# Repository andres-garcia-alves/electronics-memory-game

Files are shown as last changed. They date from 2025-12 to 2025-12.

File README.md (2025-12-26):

# Memory-Game

Arduino code for a 4 coloured memory game (Simon) 

&nbsp;

This project use the following electronic components:
- 1 x Arduino Nano v3
- 1 x Display 5621AS-1, 7-segments, 2-digit, common catode
- 4 x LEDs (red, blue, yellow & green)
- 1 x Buzzer
- 5 x Push-button
- 8 x 470 ohm resistors
- 4 x 330 ohm resistors
- 1 x Batery 9v

Notes:
- Edit `Definitions.h` to adjust configured display pins to your own display model.

&nbsp;

### Screenshots

| Schematic Diagram | PBC Layout |
|---|---|
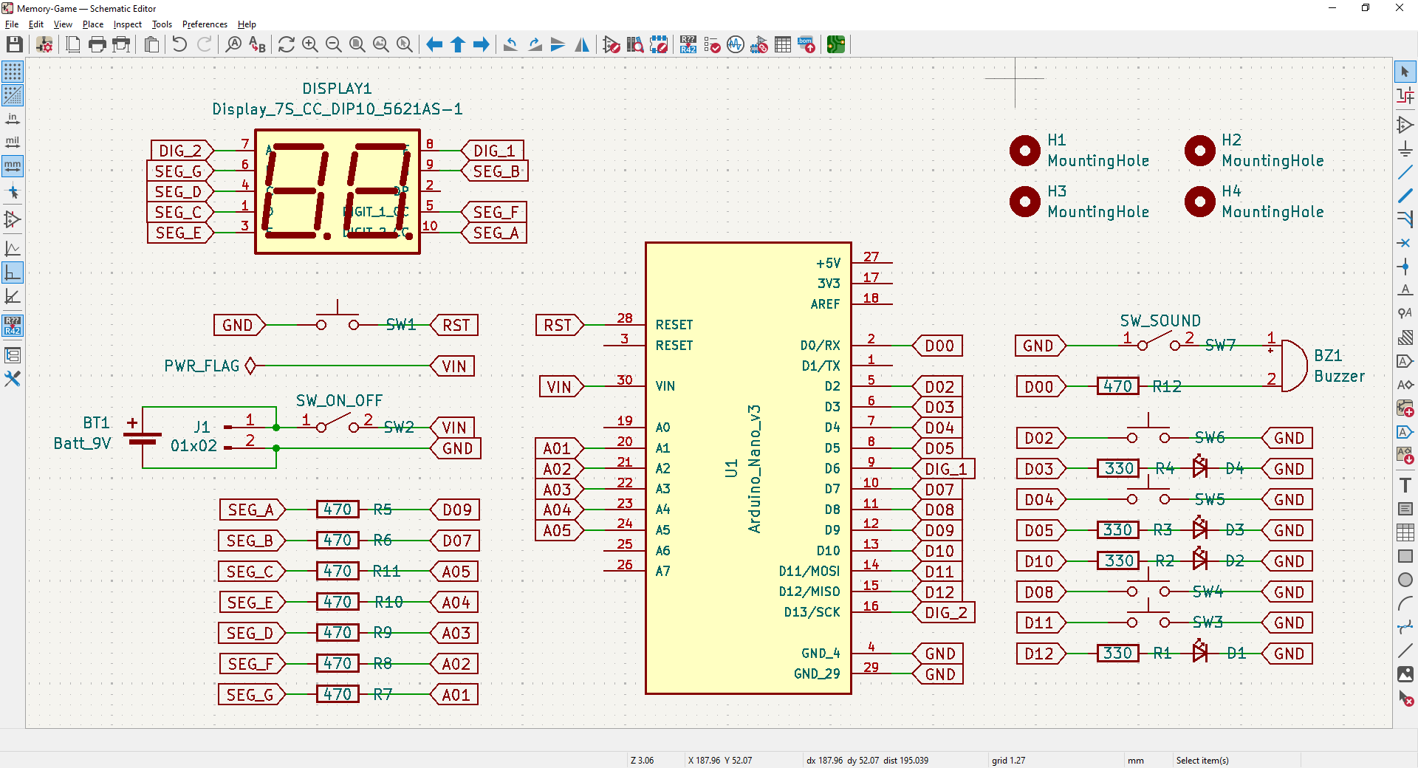
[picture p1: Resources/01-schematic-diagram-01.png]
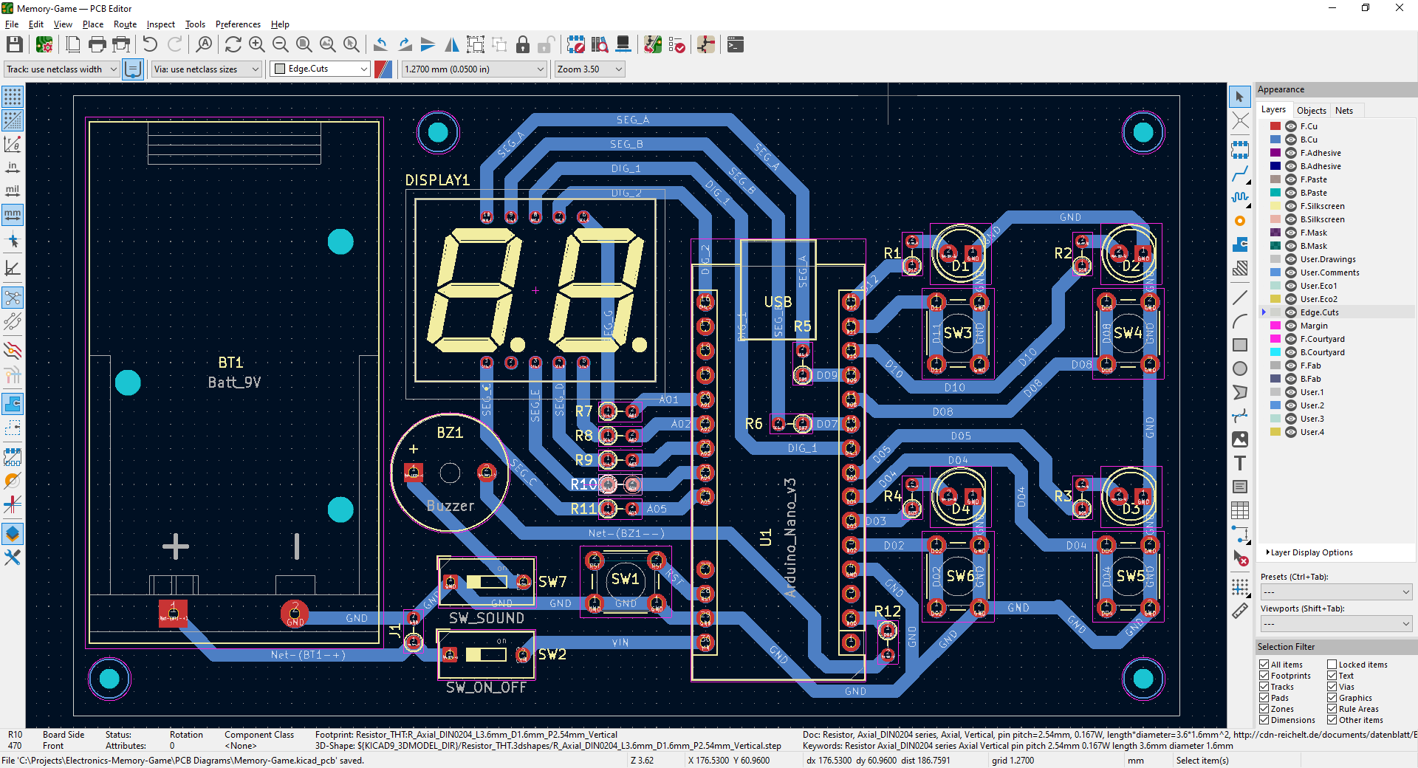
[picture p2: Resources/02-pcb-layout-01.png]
|  |  |

| PCB 3D Render | PBC 3D Render |
|---|---|
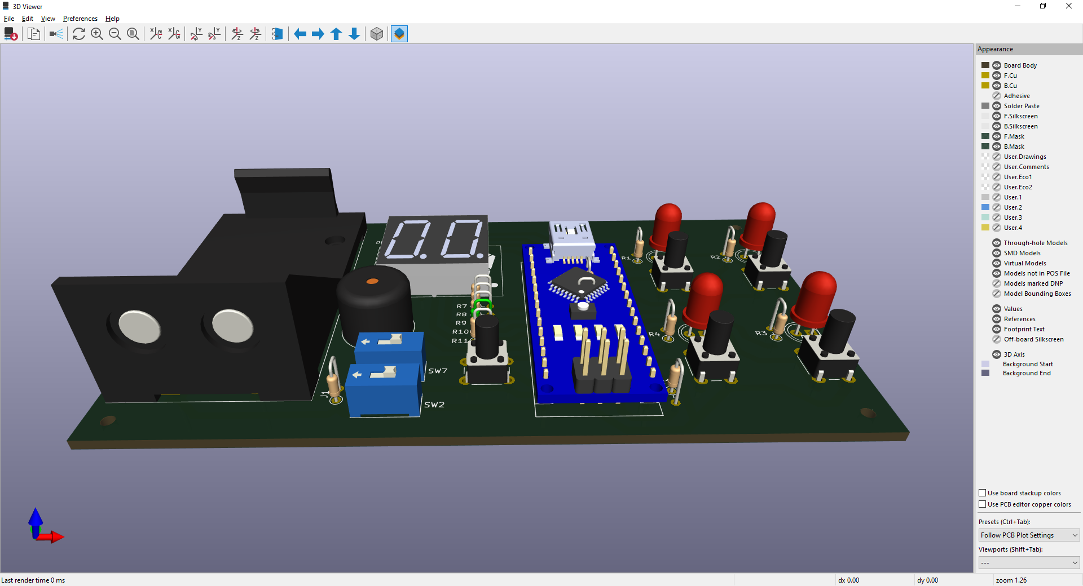
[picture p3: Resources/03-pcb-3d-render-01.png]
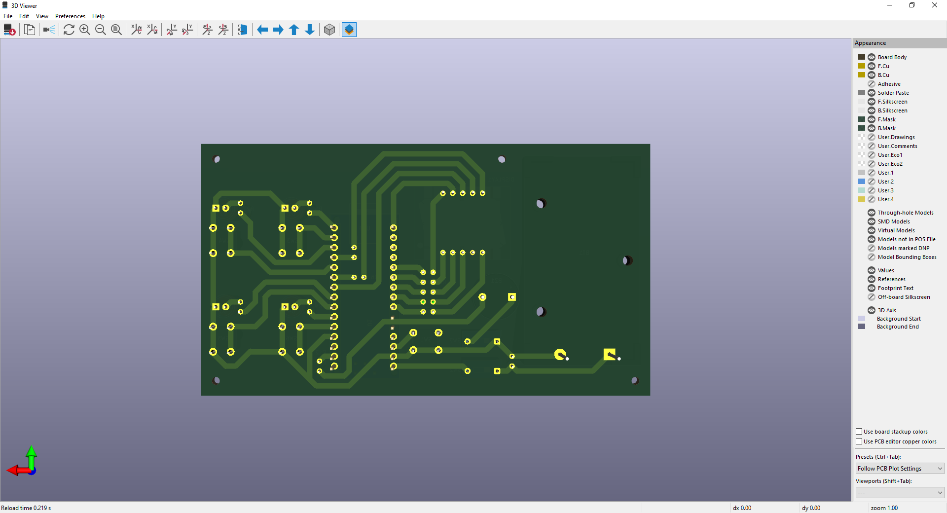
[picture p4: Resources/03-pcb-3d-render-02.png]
|  |  |

| Prototype | Building |
|---|---|
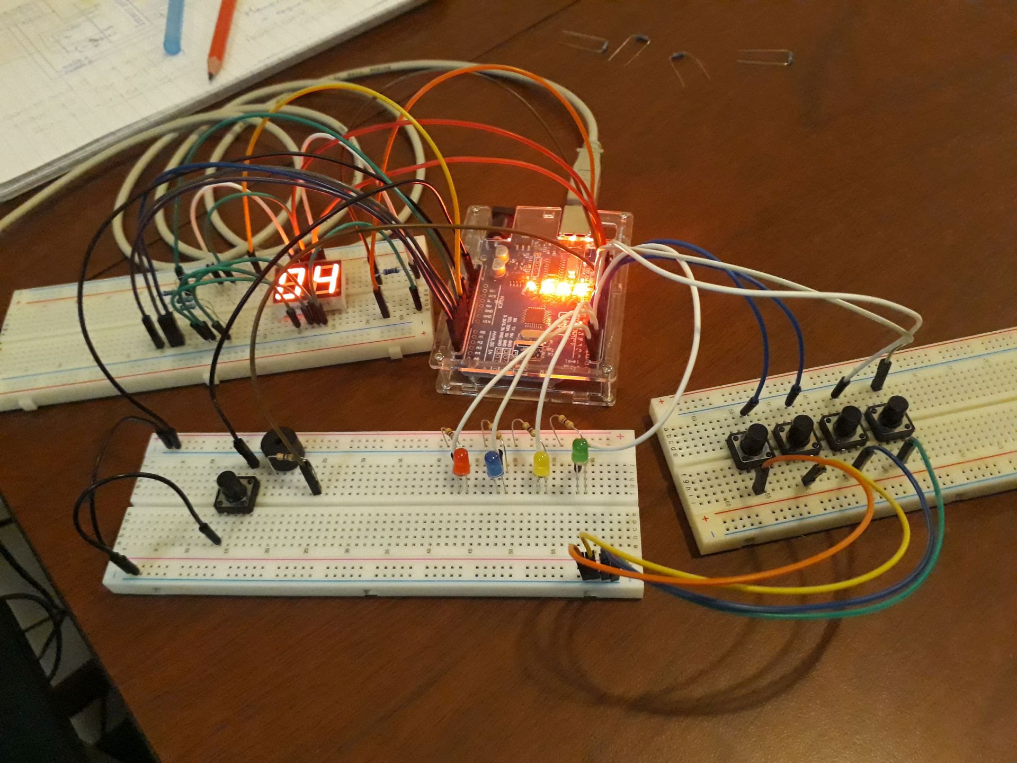
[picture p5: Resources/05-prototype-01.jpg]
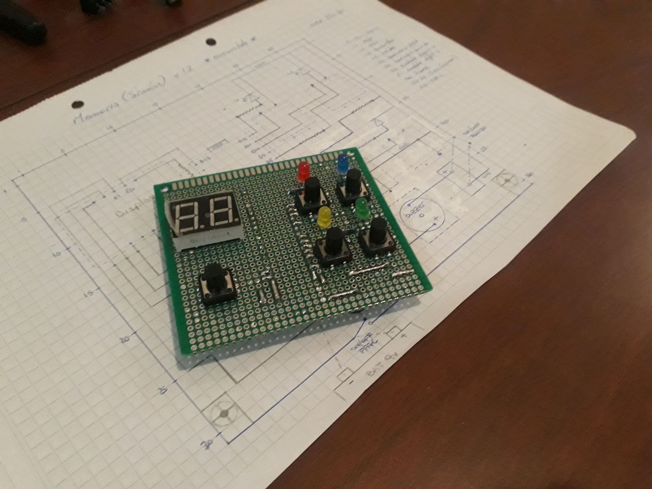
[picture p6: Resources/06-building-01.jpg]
|  |  |

| Building | Building (Finished) |
|---|---|
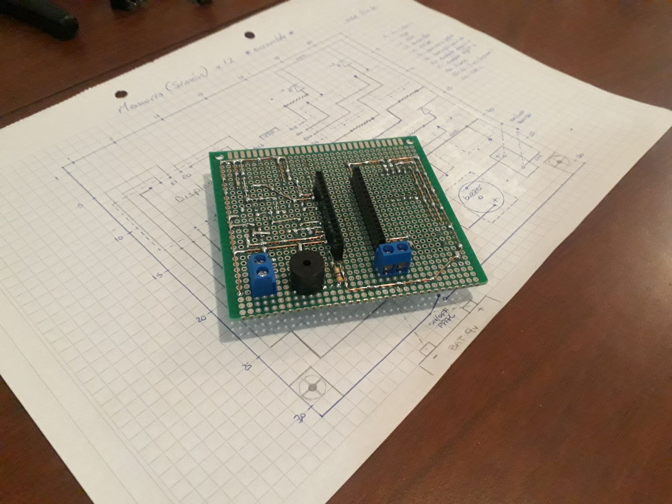
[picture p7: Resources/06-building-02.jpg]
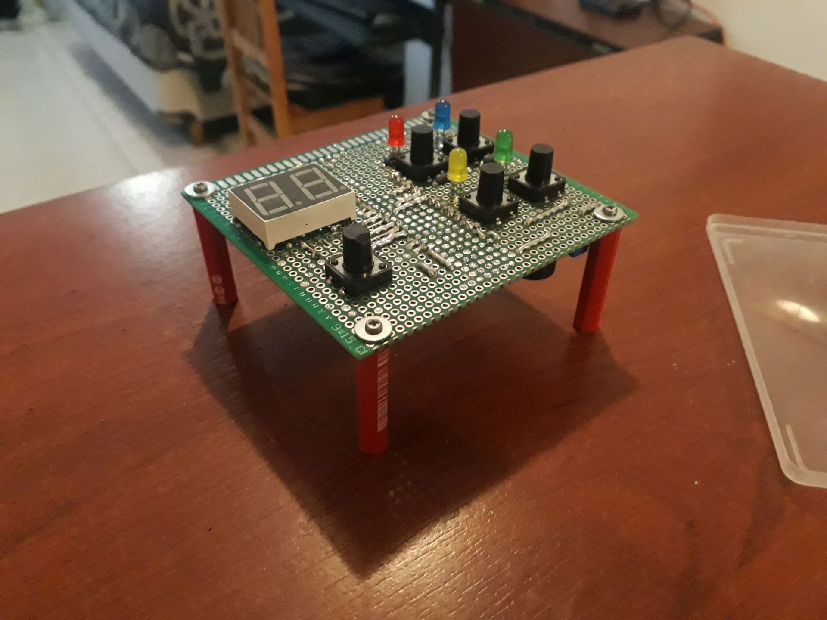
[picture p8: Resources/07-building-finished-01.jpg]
|  |  |

| Building (Finished) | Box Shaping |
|---|---|
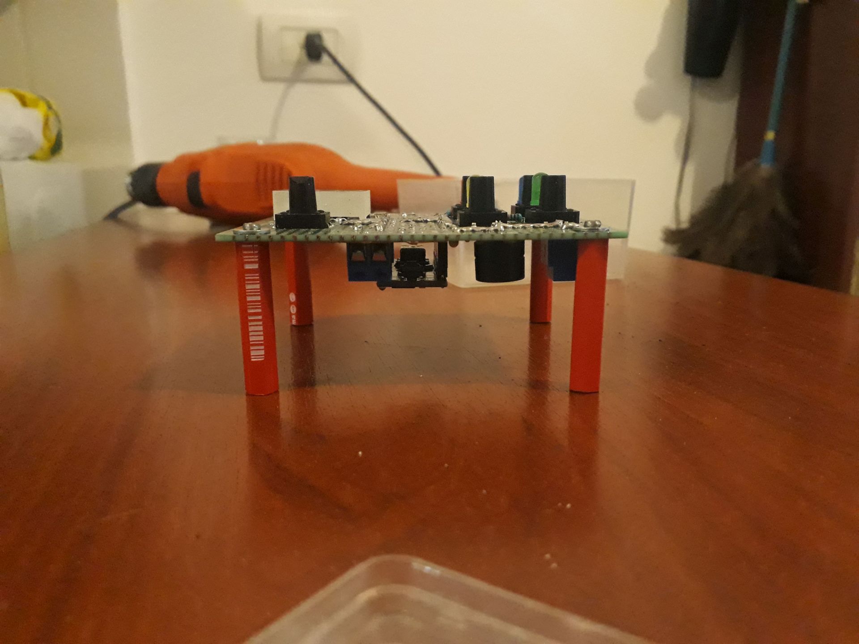
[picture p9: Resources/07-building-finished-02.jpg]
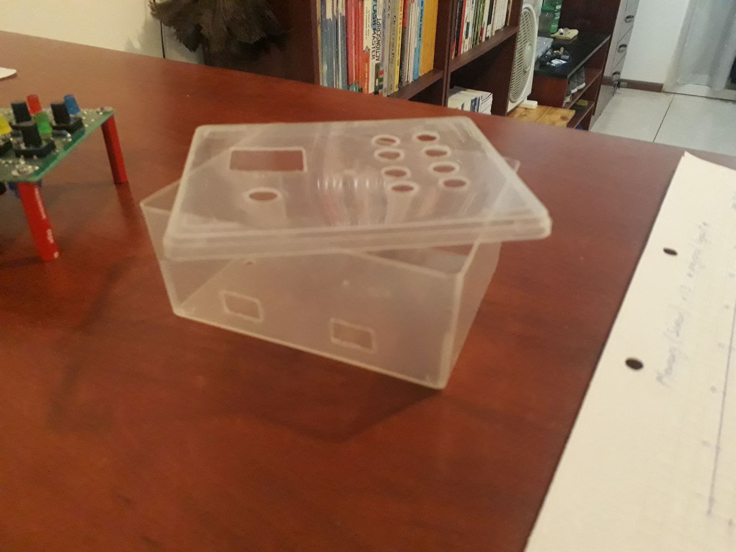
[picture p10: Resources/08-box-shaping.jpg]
|  |  |

| Project Final | Project Final (YouTube video) |
|---|---|
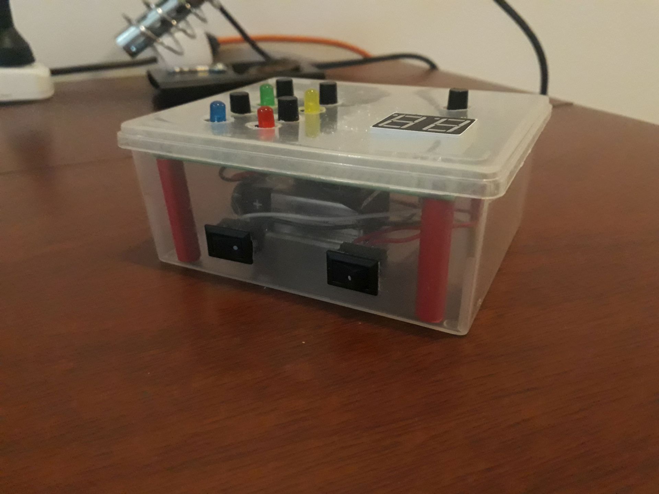
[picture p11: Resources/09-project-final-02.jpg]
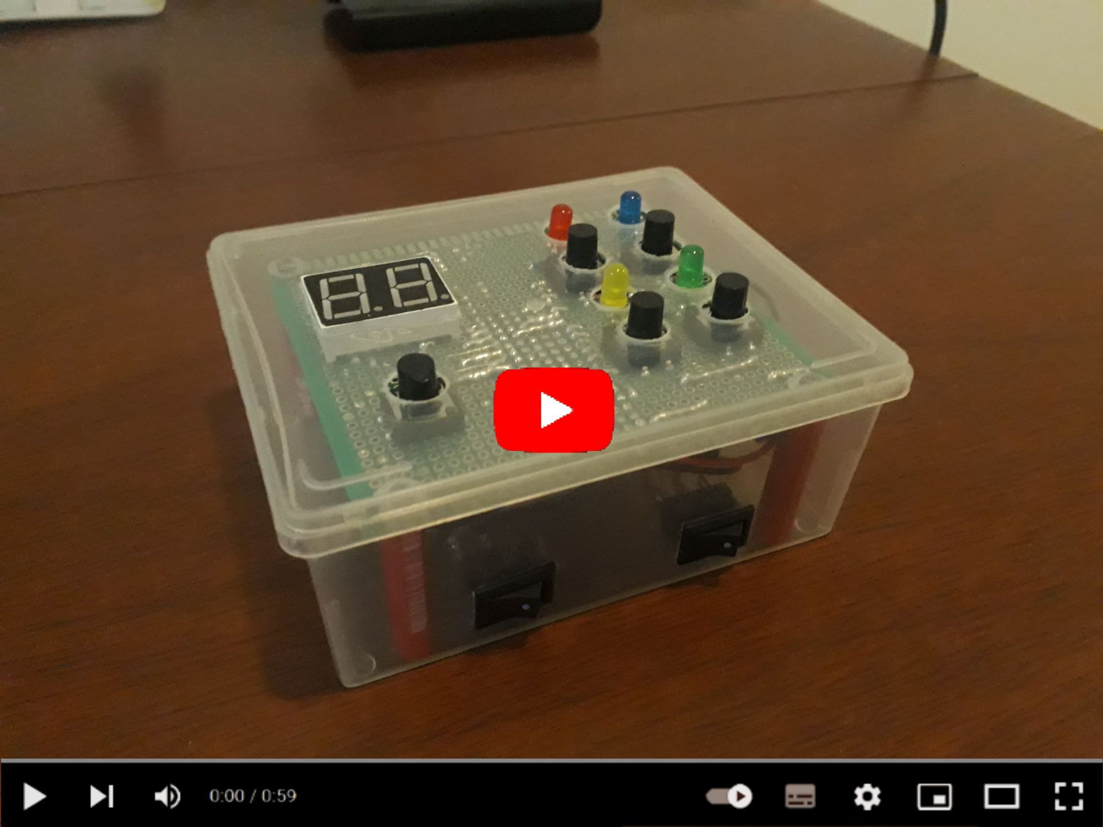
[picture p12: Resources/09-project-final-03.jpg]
(https://youtu.be/qu201MSCXys)
|  |  |

See 'Rescources' sub-folder for more pictures & videos of the project.

&nbsp;

### Version History

v1.0 (2023.03.08) - Initial release.  
v1.1 (2023.03.09) - Refactor for mudularity (adding concept of micro-commands for user inteccions).  
v1.2 (2023.03.10) - Improved animations.  
v1.3 (2023.03.15) - Pinout rearrange for easy soldering.  
v1.4 (2023.03.18) - Adding game finished sequence.  
v1.5 (2025.12.20) - Update project structure.  
v1.6 (2025.12.26) - Adding KiCAD 9 schematics and PCB diagrams.  

&nbsp;

This source code is licensed under GPL v3.0  
Please send me your feedback about this project: andres.garcia.alves@gmail.com

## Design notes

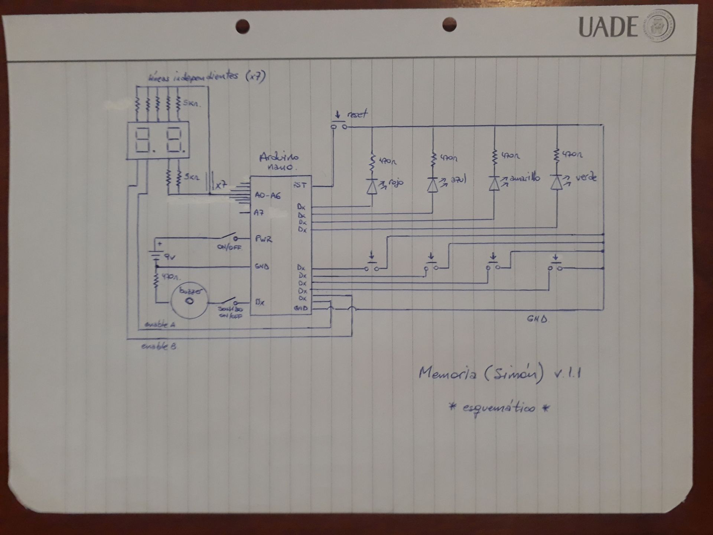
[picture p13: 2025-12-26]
Resources/01-schematic-diagram-02.jpg

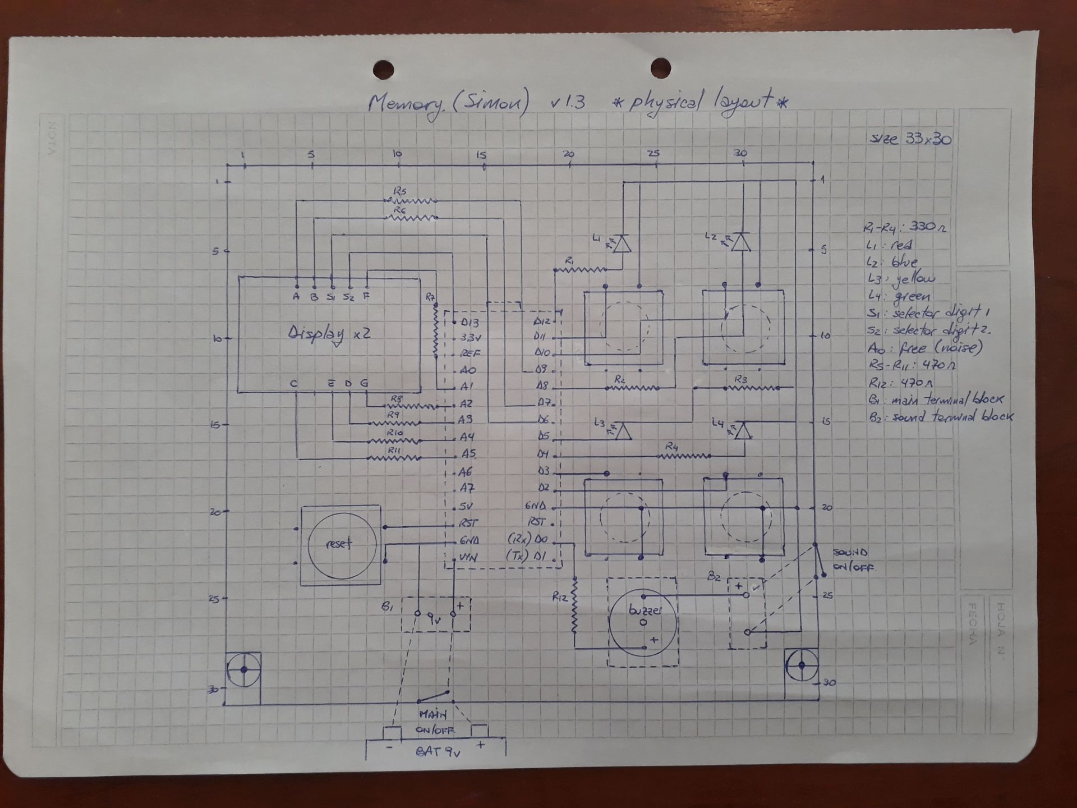
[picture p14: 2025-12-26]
Resources/02-pcb-layout-02.jpg

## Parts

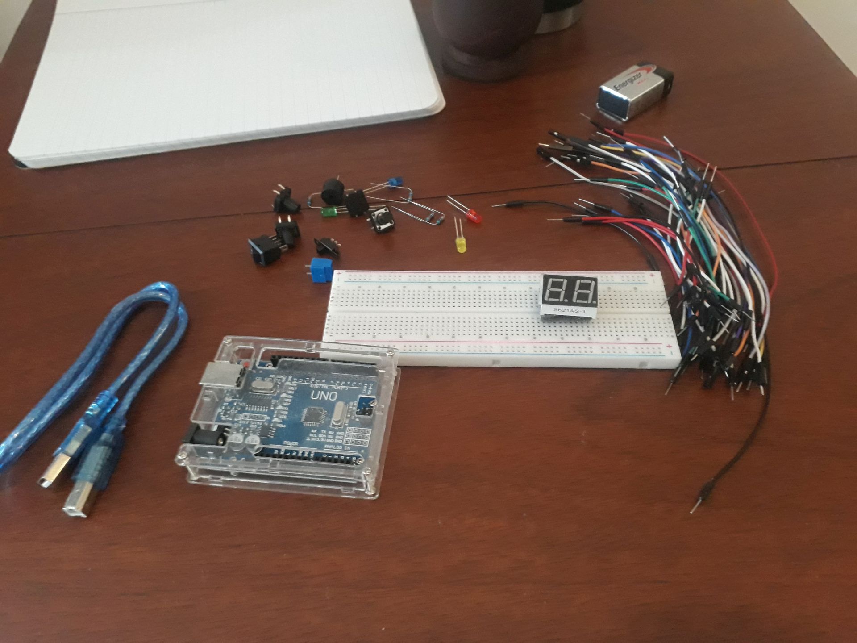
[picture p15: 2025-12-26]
Resources/04-materials.jpg

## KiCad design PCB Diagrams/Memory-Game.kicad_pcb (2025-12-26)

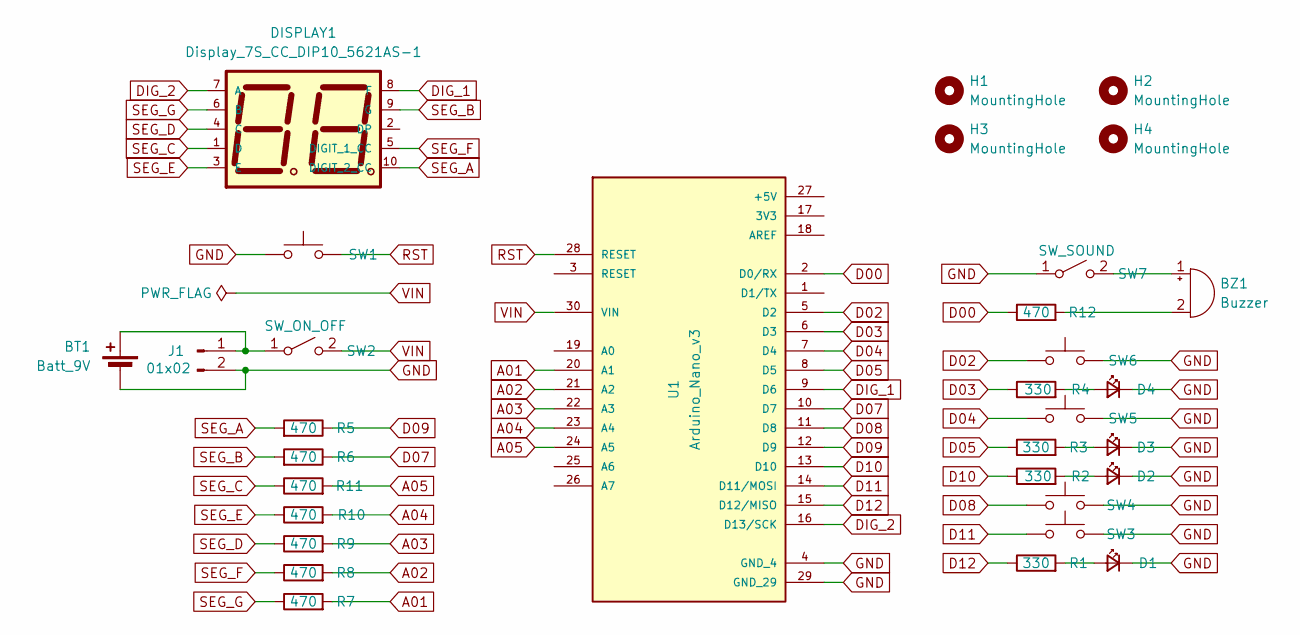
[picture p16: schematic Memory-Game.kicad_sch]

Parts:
BT1: Batt_9V; BatteryHolder_Eagle_12BH611-GR
BZ1: Buzzer; Buzzer_12x9.5RM7.6
D1, D2, D3, D4: LED; LED_D5.0mm
DISPLAY1: Display_7S_CC_DIP10_5621AS-1; Display_7S_CC_DIP10_VCC_C565S9
H1, H2, H3, H4: MountingHole; MountingHole_2mm
J1: 01x02; R_Axial_DIN0204_L3.6mm_D1.6mm_P2.54mm_Vertical
R1, R2, R3, R4: 330; R_Axial_DIN0204_L3.6mm_D1.6mm_P2.54mm_Vertical
R5, R6, R7, R8, R9, R10, R11, R12: 470; R_Axial_DIN0204_L3.6mm_D1.6mm_P2.54mm_Vertical
SW1, SW3, SW4, SW5, SW6: SW_Push; SW_PUSH_6mm_H9.5mm
SW2: SW_ON_OFF; SW_DIP_SPSTx01_Slide_9.78x4.72mm_W7.62mm_P2.54mm
SW7: SW_SOUND; SW_DIP_SPSTx01_Slide_9.78x4.72mm_W7.62mm_P2.54mm
U1: Arduino_Nano_v3

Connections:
A01: R7.2, U1.20 (A1)
A02: R8.2, U1.21 (A2)
A03: R9.2, U1.22 (A3)
A04: R10.2, U1.23 (A4)
A05: R11.2, U1.24 (A5)
D00: R12.1, U1.2 (D0/RX)
D02: SW6.1, U1.5 (D2)
D03: R4.1, U1.6 (D3)
D04: SW5.1, U1.7 (D4)
D05: R3.1, U1.8 (D5)
D07: R6.1, U1.10 (D7)
D08: SW4.1, U1.11 (D8)
D09: R5.1, U1.12 (D9)
D10: R2.1, U1.13 (D10)
D11: SW3.1, U1.14 (D11/MOSI)
D12: R1.1, U1.15 (D12/MISO)
DIG_1: DISPLAY1.8 (F), U1.9 (D6)
DIG_2: DISPLAY1.7 (A), U1.16 (D13/SCK)
GND: BT1.2 (-), D1.1 (K), D2.1 (K), D3.1 (K), D4.1 (K), J1.2, SW1.1, SW3.2, SW4.2, SW5.2, SW6.2, SW7.1 (A), U1.4 (GND_4), U1.29 (GND_29)
unnamed: BT1.1 (+), J1.1, SW2.1 (A)
unnamed: BZ1.1 (+), SW7.2 (B)
unnamed: BZ1.2 (-), R12.2
unnamed: D1.2 (A), R1.2
unnamed: D2.2 (A), R2.2
unnamed: D3.2 (A), R3.2
unnamed: D4.2 (A), R4.2
RST: SW1.2, U1.28 (RESET)
SEG_A: DISPLAY1.10 (DIGIT_2_CC), R5.2
SEG_B: DISPLAY1.9 (G), R6.2
SEG_C: DISPLAY1.1 (D), R11.1
SEG_D: DISPLAY1.4 (C), R9.1
SEG_E: DISPLAY1.3 (E), R10.1
SEG_F: DISPLAY1.5 (DIGIT_1_CC), R8.1
SEG_G: DISPLAY1.6 (B), R7.1
VIN: SW2.2 (B), U1.30 (VIN)

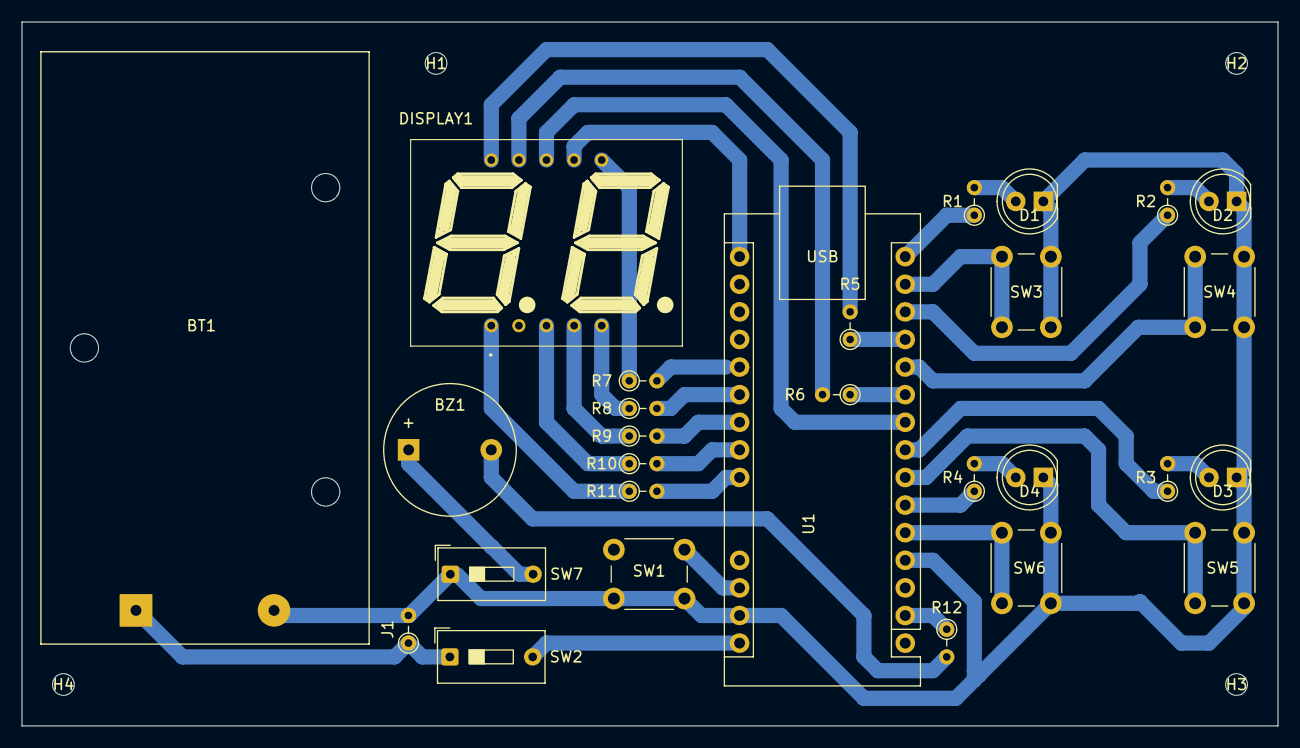
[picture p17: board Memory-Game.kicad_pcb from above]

Board: 2 copper layers, 115.6 x 64.8 mm, 32 parts (0 on the bottom side), 35 nets.

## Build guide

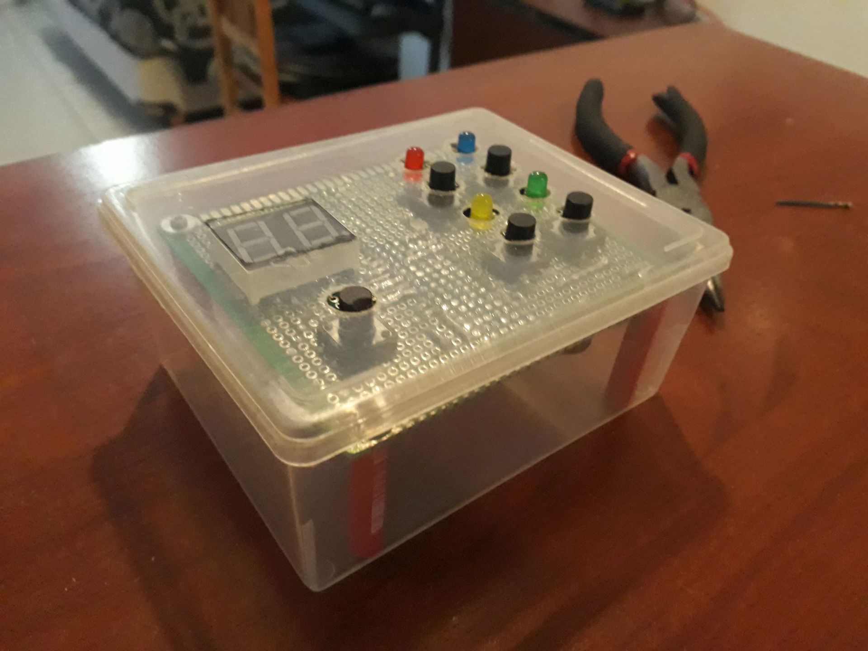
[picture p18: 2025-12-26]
Resources/07-building-finished-03.jpg

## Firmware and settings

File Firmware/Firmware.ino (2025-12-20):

/*
Memory Game v1.4

Created by: Andres Garcia Alves <andres.garcia.alves@gmail.com>
Microcontroller: Arduino Nano (ATMega328 @16Mhz)

Version 1.0, 2023.03.08 - Initial release.
Version 1.1, 2023.03.09 - Refactor for mudularity (adding concept of micro-commands for user inteccions).
Version 1.2, 2023.03.10 - Improved animations.
Version 1.3, 2023.03.15 - Pinout rearrange for easy soldering.
Version 1.4, 2023.03.18 - Adding game finished sequence.

This source code is licensed under GPL v3.0

Pinout (2 digit multiplexed 7-segment display):

      ***(A)***
  (F) *       * (B)
      ***(G)***
  (E) *       * (C)
      ***(D)***
*/

#include "Definitions.h"
#include "Debug.h"
#include "Utilities.h"
#include "Display_2d.h"
#include "MessagesHelper.h"

void setup() {

  #if DEBUG
  Serial.begin(9600);
  #endif

  pinMode(DISPLAY_DIGIT_1, OUTPUT); // left digit
  pinMode(DISPLAY_DIGIT_0, OUTPUT); // right digit

  pinMode(DISPLAY_LED_A, OUTPUT);
  pinMode(DISPLAY_LED_B, OUTPUT);
  pinMode(DISPLAY_LED_C, OUTPUT);
  pinMode(DISPLAY_LED_D, OUTPUT);
  pinMode(DISPLAY_LED_E, OUTPUT);
  pinMode(DISPLAY_LED_F, OUTPUT);
  pinMode(DISPLAY_LED_G, OUTPUT);
  
  pinMode(LED_RED, OUTPUT);
  pinMode(LED_BLUE, OUTPUT);
  pinMode(LED_YELLOW, OUTPUT);
  pinMode(LED_GREEN, OUTPUT);
  pinMode(BUTTON_RED, INPUT_PULLUP);
  pinMode(BUTTON_BLUE, INPUT_PULLUP);
  pinMode(BUTTON_YELLOW, INPUT_PULLUP);
  pinMode(BUTTON_GREEN, INPUT_PULLUP);
  
  pinMode(BUZZER, OUTPUT);
  
  // get some noise value from A0
  randomSeed(analogRead(RANDOM_NOISE));
}

void loop() {

  runCommands();                // run generated commands
  updateDisplay(currentLevel);  // update display & move to next digit
  
  // game control
  if (gameMode == eGameMode::STARTING && noPendingCommands()) {
    initializeMessage();
  }
  else if (gameMode == eGameMode::SEQUENCE_MODE && noPendingCommands()) {
    sequenceMessage();
  }
  else if (gameMode == eGameMode::PLAYER_MODE && noPendingCommands()) {
    stInput input = checkInput();
    if (input.hasData && !debounced)      { debounceMessage(); }
    else if (input.hasData && debounced)  { processInputMessage(input); }
  }
  else if (gameMode == eGameMode::WRONG_INPUT && noPendingCommands()) {
    wrongInputMessage();
  }
  else if (gameMode == eGameMode::ENDING && noPendingCommands()) {
    endingMessage();
  }

  delay(10);
}

stInput checkInput() {

  bool redButton = !digitalRead(BUTTON_RED);
  bool blueButton = !digitalRead(BUTTON_BLUE);
  bool yellowButton = !digitalRead(BUTTON_YELLOW);
  bool greenButton = !digitalRead(BUTTON_GREEN);

  stInput input;
  input.hasData = redButton || blueButton || yellowButton || greenButton;
  input.redButton = redButton;
  input.blueButton = blueButton;
  input.yellowButton = yellowButton;
  input.greenButton = greenButton;

  return input;
}

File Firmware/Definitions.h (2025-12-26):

#ifndef DEFINITIONS_H
#define DEFINITIONS_H

// digit-selector & display 7-segment pins
#define DISPLAY_DIGIT_1 6   // left digit
#define DISPLAY_DIGIT_0 13  // right digit

#define DISPLAY_LED_A   9
#define DISPLAY_LED_B   7
#define DISPLAY_LED_C   A5
#define DISPLAY_LED_D   A3
#define DISPLAY_LED_E   A4
#define DISPLAY_LED_F   A1
#define DISPLAY_LED_G   A2

// LEDs, bottons & other pins
#define LED_RED         12
#define LED_BLUE        10
#define LED_YELLOW      5
#define LED_GREEN       3
#define BUTTON_RED      11
#define BUTTON_BLUE     8
#define BUTTON_YELLOW   4
#define BUTTON_GREEN    2

#define BUZZER          0
#define RANDOM_NOISE    A0

// misc
#define GAME_LEVELS     50  // less than 600 free bytes of dynamic memory turns into a stack overflow
#define QUEUE_SIZE      155 // GAME_LEVELS * 3 + 5

#define FRECUENCY_FACTOR  10
#define DURATION_FACTOR   10

// enums
enum class eGameMode : byte { NONE = 0, STARTING = 1, SEQUENCE_MODE = 2, PLAYER_MODE = 3, WRONG_INPUT = 4, ENDING = 5 };

enum class eCmdType : byte { INIT = 0, GAME_MODE = 1, WAIT = 2, DEBOUNCE = 3, BUTTON = 4, LED = 5, BEEP = 6, WRONG = 7, END = 8 };
enum class eWait : byte { ZERO = 0, DEBOUNCE = 5, ANIM_HALF = 20, ANIM_FULL = 40, START = 150, WRONG = 255 }; // values x 10
enum class eColor : byte { NONE = 0, RED = 1, BLUE = 2, YELLOW = 3, GREEN = 4 };

enum class eToneFrecuency : byte { WRONG = 10, RED = 50, BLUE = 60, YELLOW = 70, GREEN = 80 };  // values x 10
enum class eToneDuration : byte { ANIM_HALF = 20, ANIM_FULL = 40, WRONG = 255, END = 255 };     // values x 10

// data structures
struct stInput { bool hasData; bool redButton; bool blueButton; bool yellowButton; bool greenButton; };
struct stBuzzer { byte frecuency; byte duration; };
struct stCommand { eCmdType cmdType; eWait wait; eGameMode gameMode; byte input; eColor color; stBuzzer buzzer; };

// variables
bool debounced;
byte currentLevel;
eGameMode gameMode = eGameMode::STARTING;
eColor colorSequence[GAME_LEVELS];
eColor playerSequence[GAME_LEVELS];

// aux variables
byte emptyInput;
stBuzzer emptyBuzzer;

#endif
